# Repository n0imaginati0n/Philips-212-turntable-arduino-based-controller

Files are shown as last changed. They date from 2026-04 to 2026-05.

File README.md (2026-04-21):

# Philips-212-turntable-arduino-based-controller

A controller upgrade for the classic Philips 212 Hi-Fi turntable.
Replaces all touch switch, motor control, and auto-off functions with an Arduino Uno clone

Files include Arduino sketch and KiCad files

Fork of the

[lens42 project](https://github.com/lens42/Philips-212-turntable-arduino-based-controller)

[Details:](https://lensprojects.wordpress.com/2019/01/08/philips-212-turntable-controller-upgrade/)

# Improvements

* Use of the Ardino Pro Mini
* Self-made PCB. There are not so many parts there, it can be etched at home
* review schematics
    - add necessay loading on the LM780x. According to the datasheet, minimal current is 5..10 mA.
    - LM780x don't like to work on big capacitance load - they need protection diodes
    - small filtering caps on the sensors input to filter noise. input cirquit can be taken from original GA212 schematics
    - resistance in the MOSFET gate cirquit to limit the pulse current through MCU output
    - allow TH componets usage, reuse some items from original board
    - IP pins can be assigned better to make less croddings on the PCB
    - sensor button connections can be done better. but analog curcit rules should be taken into account
    - as I plan to etch teh single-layer board at home, I will use tow heatsinks for LM780x instead of the PCB polygons. There 
        is a lot of space under the PCB.
* Programming UART pins and reset button on the board. Pro Mini hasn't USB socket.
* Review the firmware
    - make it interactive
    - all initially predefined values can be set by UART
    - keep configuration values in the FLASH

# Arduino Power

Almost all Arduino boards has an LDO onboard. This LDO allows up to 16V input and can supply arduino and external cirquit 
with the +3.3V/+5V <150mA power according to the Arduino version. All the MCU ATMEGA328 allow both +3.3V and +5V power. The 
difference is that on lower voltage Arduino works stable with less crystal frequency. That is why +3.3V has 8MHz crystal and 
+5V has 16MHz crystal. Any version of the Arduino Pro Mini can safely be supplied with the +5V.

LM393 can operate with power in +2V..+36V range, means it can be perfectly powered from any version of the Arduino. It 
cosumes <20mA, this current is a maximal sink current and should be lower than that.

Unfortunately, my Arduino LDO is broken because of the previous experiments, that is why I kept the external LDO here and lead 
the +5V to the Arduino Vcc input. Vcc - is a direct way to teh Arduino power excluding on-baord LDO.

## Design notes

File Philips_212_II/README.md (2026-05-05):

---
title: Philips GA212 firmware
---

# Implementation description

This firmware implemented as a list of tasks. Each task has 'init' and 'loop' function.
They are called from 'init' and 'loop' functions of the sketch appropriately. It is not RTOS,
it has no guaranteed response time to events, but it still allows to execute many 
simultaneous functions. The only rules: don't block the execution and be fast. better 
split long operation over more than one calls of 'loop' task function. Tasks related to 
interrupts has interrupt handlers in their own compilation units.

## LEDs task

light LEDs according to the current mode.

## Autostop task

if motor is on, track the value of the photosensor and switch teh mode to OFF as fast as 
photosensor value will show end of plate. the sensing value stored in configuration and 
can be set from shell

## Buttons task

this task implements simple de-bouncing for buttons and changes the state accordingly to
pressed buttons. De-bouncing algorithm is pretty common: it waits until the bouncing stop, 
waits for some time, prove, that button strate kept pressed and sign about event the main 
loop. only pins D2 and D3 can generate interrupt in this MCU. all the state tracking done
manually using digitalRead()

## Speed task

this task loads appropriate potentiometer value, calculate necessary PWM value and set it 
to the motor acceleration. as potentiometers aren't really precise, they left to function 
in a specific range. i.e. their value after appropriate scaling will be added to the 
configuration stored value to get result acceleration. to make it working, the configuration 
value can be set from shell. software will monitor not a PWM, but a tacho value, which is 
measured in microseconds. 33 RPM has period approximately 26700 us, 45 RPM has period 
approximately 19250 us in my case. as PWM value going to be not absolute, but relative - 
increase to shortend measured period and decrease to extend it, it is important to evaluate 
new PWM value only once per period measurement. otherwise intertia will be introduced - the PWM 
value will be corrected multiple times per period measurement trying to correct period and 
overcomensate in result

## Shell task

this task is responsible for primitive shell available on serial programming port. the shell 
can print current configuration, set new configuration values, switch on debug monitoring. shell 
is asynchronous, that is why it can react with a small delay

# Implementation Status

- [x] LEDs task
  - [x] Implemntation
  - [x] Monitoring
- [x] Shell task
  - [x] Implementation
  - [x] Monitoring
- [x] Autostop task
  - [x] Implemntation
  - [x] Monitoring
- [x] Buttons task
  - [x] Implementation
  - [x] Monitoring
- [x] Speed task
  - [ ] Implementation
  - [x] Monitoring
- [x] Configuration
  - [x] EEPROM storage
  - [x] use by getter
  - [x] update by setters

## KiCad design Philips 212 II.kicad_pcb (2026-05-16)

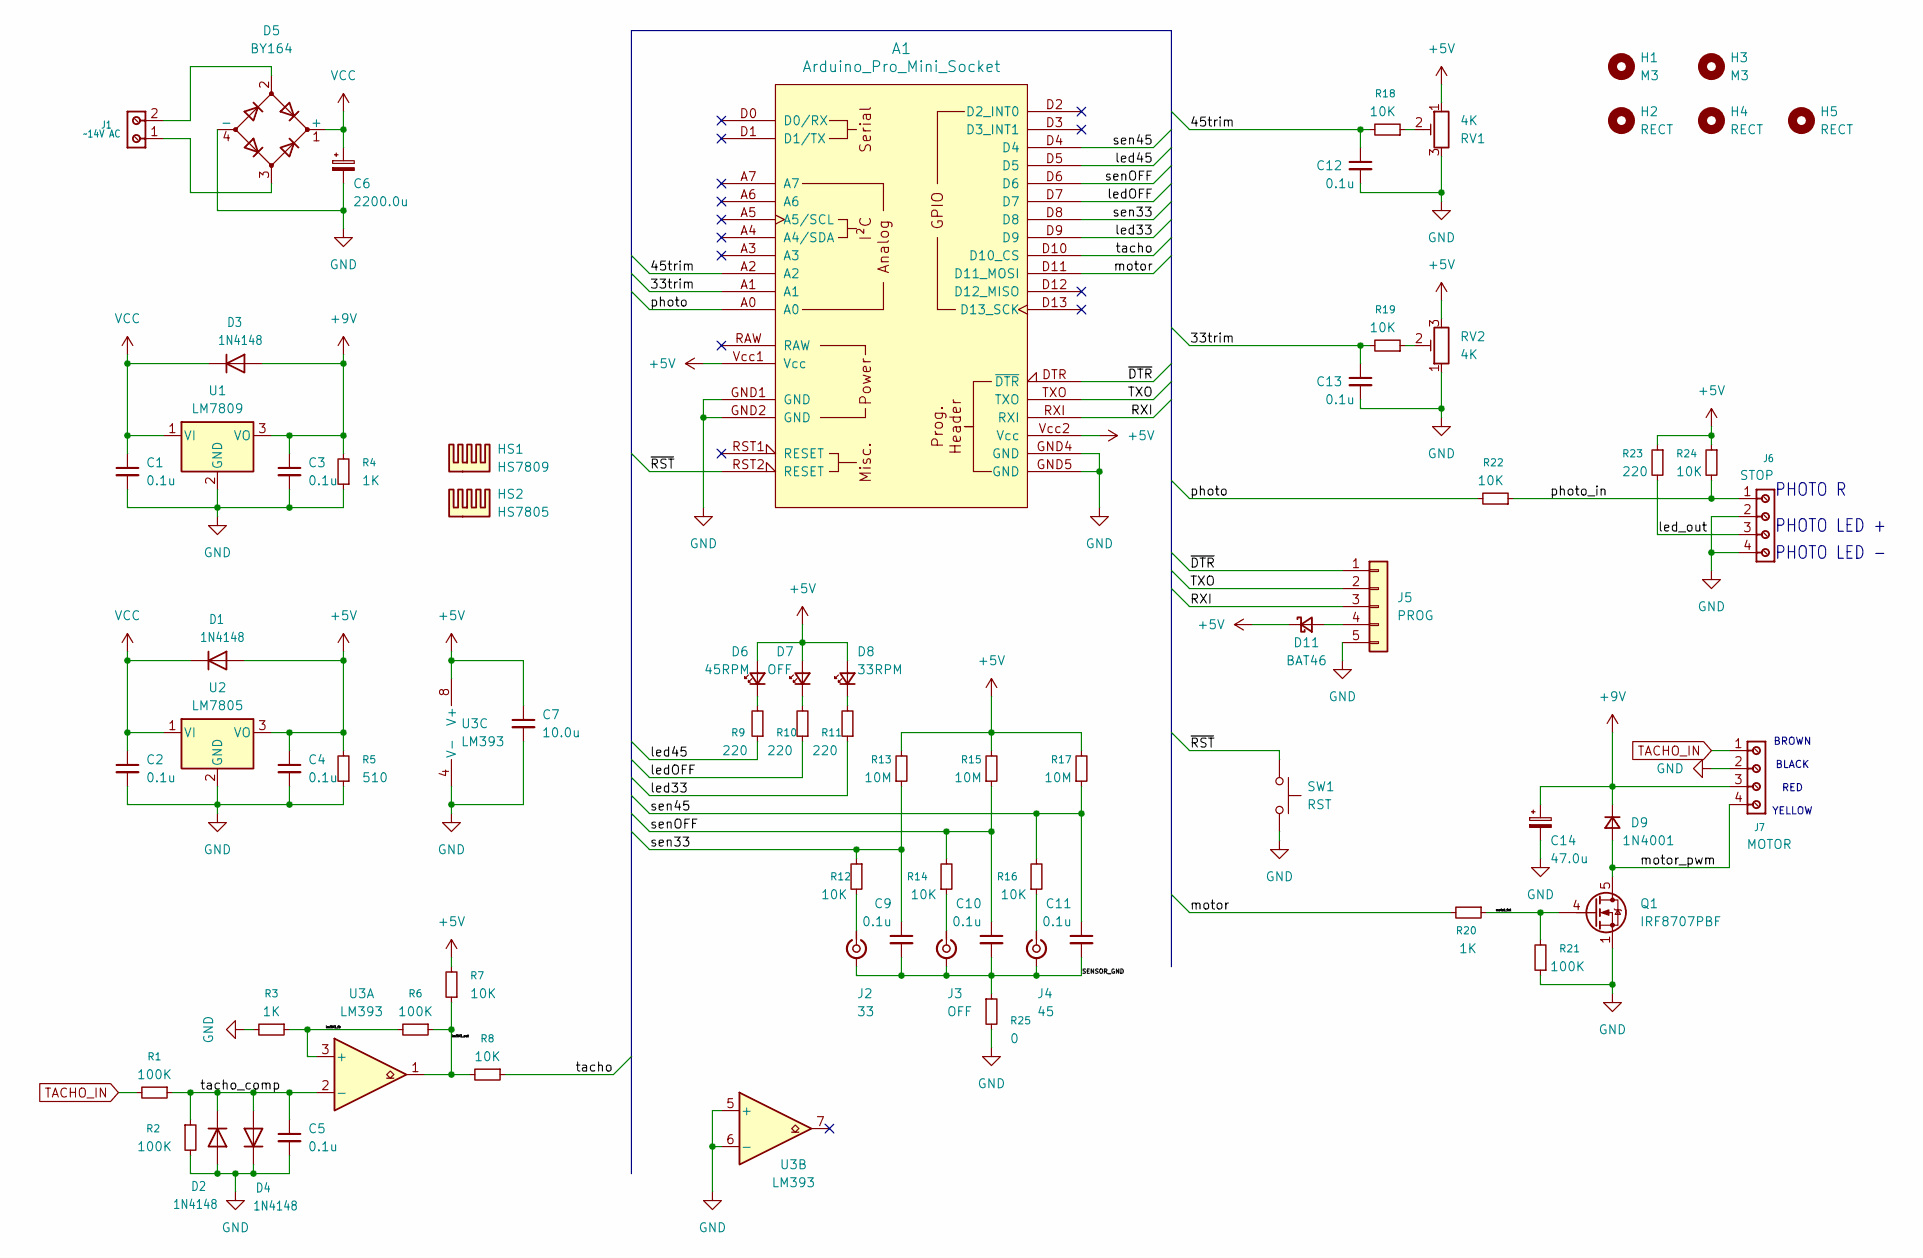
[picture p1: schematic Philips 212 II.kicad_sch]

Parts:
A1: Arduino_Pro_Mini_Socket
C1, C2, C3, C4, C5, C9, C10, C11, C12, C13: 0.1u; C_0805_2012Metric_Pad1.18x1.45mm_HandSolder
C6: 2200.0u; CP_Radial_D16.0mm_P7.50mm
C7: 10.0u; CP_Radial_D8.0mm_P3.50mm
C14: 47.0u; CP_Radial_D8.0mm_P3.50mm
D1, D3: 1N4148; D_MELF_Handsoldering
D2, D4: 1N4148; D_DO-35_SOD27_P7.62mm_Horizontal
D5: BY164; Diode_Bridge_19.0x3.5x10.0mm_P5.0mm
D6: 45RPM; LED_D5.0mm_Horizontal_O6.35mm_Z15.0mm
D7: OFF; LED_D5.0mm_Horizontal_O6.35mm_Z15.0mm
D8: 33RPM; LED_D5.0mm_Horizontal_O6.35mm_Z15.0mm
D9: 1N4001; D_DO-41_SOD81_P10.16mm_Horizontal
D11: BAT46; D_DO-35_SOD27_P7.62mm_Horizontal
H1, H3: M3; MountingHole_3.2mm_M3
H2, H4, H5: RECT; MountingHole_6mm
HS1: HS7809; FISHER-FK211-32_TO220_Horizontal
HS2: HS7805; FISHER-FK211-32_TO220_Horizontal
J1: ~14V AC; Altech_AK100_1x02_P5.00mm
J2: 33; Altech_AK100_1x02_P5.00mm
J3: OFF; Altech_AK100_1x02_P5.00mm
J4: 45; Altech_AK100_1x02_P5.00mm
J5: PROG; PinHeader_1x05_P2.54mm_Vertical
J6: STOP; Altech_AK100_1x04_P5.00mm
J7: MOTOR; Altech_AK100_1x04_P5.00mm
Q1: IRF8707PBF; PowerPAK_SO-8_Single
R1, R2, R21: 100K; R_0805_2012Metric_Pad1.20x1.40mm_HandSolder
R3: 1K; R_0805_2012Metric_Pad1.20x1.40mm_HandSolder
R4, R20: 1K; R_Axial_DIN0207_L6.3mm_D2.5mm_P7.62mm_Horizontal
R5: 510; R_Axial_DIN0207_L6.3mm_D2.5mm_P7.62mm_Horizontal
R6: 100K; R_Axial_DIN0207_L6.3mm_D2.5mm_P7.62mm_Horizontal
R7, R12, R14, R16, R18, R19, R22, R24: 10K; R_0805_2012Metric_Pad1.20x1.40mm_HandSolder
R8: 10K; R_Axial_DIN0207_L6.3mm_D2.5mm_P7.62mm_Horizontal
R9, R10, R11, R23: 220; R_Axial_DIN0207_L6.3mm_D2.5mm_P7.62mm_Horizontal
R13, R15, R17: 10M; R_Axial_DIN0411_L9.9mm_D3.6mm_P15.24mm_Horizontal
R25: 0; R_0805_2012Metric_Pad1.20x1.40mm_HandSolder
RV1, RV2: 4K; Potentiometer_ACP_CA14V-15_Vertical_Hole
SW1: RST; SW_PUSH_6mm
U1: LM7809; TO-220-3_Horizontal_TabDown
U2: LM7805; TO-220-3_Horizontal_TabDown
U3: LM393; SOIC-8_3.9x4.9mm_P1.27mm

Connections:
+5V: A1.Vcc1 (Vcc), A1.Vcc2 (Vcc), C4.1, C7.1, D1.2 (A), D6.2 (A), D7.2 (A), D8.2 (A), D11.1 (K), R5.2, R7.2, R13.2, R15.2, R17.2, R23.1, R24.1, RV1.1, RV2.3, U2.3 (VO), U3.8 (V+)
+9V: C3.1, C14.1, D3.2 (A), D9.1 (K), J7.3, R4.2, U1.3 (VO)
/33trim: A1.A1, C13.1, R19.2
/45trim: A1.A2, C12.1, R18.2
/RXI: A1.RXI, J5.3
/SENSOR_GND: C9.2, C10.2, C11.2, J2.2 (Ext), J3.2 (Ext), J4.2 (Ext), R25.1
/TXO: A1.TXO, J5.2
/led33: A1.D9, R11.1
/led45: A1.D5, R9.1
/ledOFF: A1.D7, R10.1
/led_out: J6.3, R23.2
/lm393_fb: R3.1, R6.2, U3.3 (+)
/lm393_out: R6.1, R7.1, R8.2, U3.1
/motor: A1.D11 (D11_MOSI), R20.2
/motor_pwm: D9.2 (A), J7.4, Q1.5 (D)
/motot_fet: Q1.4 (G), R20.1, R21.2
/photo: A1.A0, R22.2
/photo_in: J6.1, R22.1, R24.2
/sen33: A1.D8, C9.1, R12.1, R13.1
/sen45: A1.D4, C11.1, R16.2, R17.1
/senOFF: A1.D6, C10.1, R14.2, R15.1
/tacho: A1.D10 (D10_CS), R8.1
/tacho_comp: C5.1, D2.1 (K), D4.2 (A), R1.1, R2.1, U3.2 (-)
/~DTR: A1.DTR (~DTR), J5.1
/~RST: A1.RST2 (RESET), SW1.1
GND: A1.GND1 (GND), A1.GND2 (GND), A1.GND4 (GND), A1.GND5 (GND), C1.2, C2.2, C3.2, C4.2, C5.2, C6.2, C7.2, C12.2, C13.2, C14.2, D2.2 (A), D4.1 (K), D5.4 (-), J5.5, J6.2, J6.4, J7.2, Q1.1 (S), Q1.2 (S), Q1.3 (S), R2.2, R3.2, R4.1, R5.1, R21.1, R25.2, RV1.3, RV2.1, SW1.2, U1.2 (GND), U2.2 (GND), U3.4 (V-), U3.5 (+), U3.6 (-)
unnamed: D5.2, J1.2
unnamed: D5.3, J1.1
unnamed: D6.1 (K), R9.2
unnamed: D7.1 (K), R10.2
unnamed: D8.1 (K), R11.2
unnamed: D11.2 (A), J5.4
unnamed: J2.1 (In), R12.2
unnamed: J3.1 (In), R14.1
unnamed: J4.1 (In), R16.1
unnamed: R18.1, RV1.2
unnamed: R19.1, RV2.2
TACHO_IN: J7.1, R1.2
VCC: C1.1, C2.1, C6.1, D1.1 (K), D3.1 (K), D5.1 (+), U1.1 (VI), U2.1 (VI)

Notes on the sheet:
PHOTO R
PHOTO LED -
BROWN BLACK RED YELLOW
PHOTO LED +

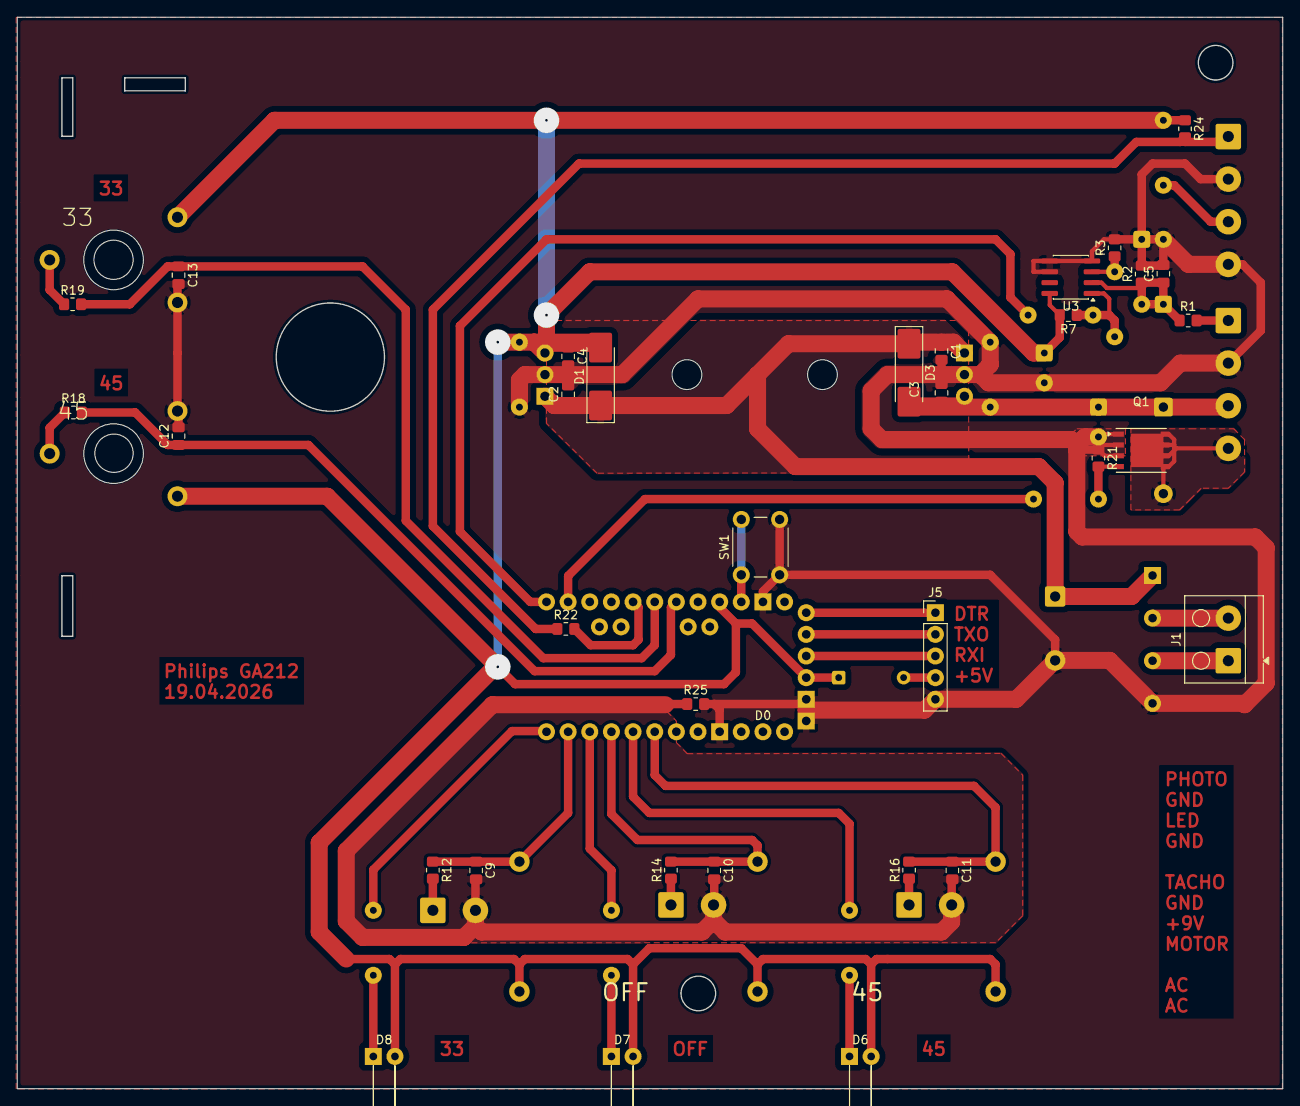
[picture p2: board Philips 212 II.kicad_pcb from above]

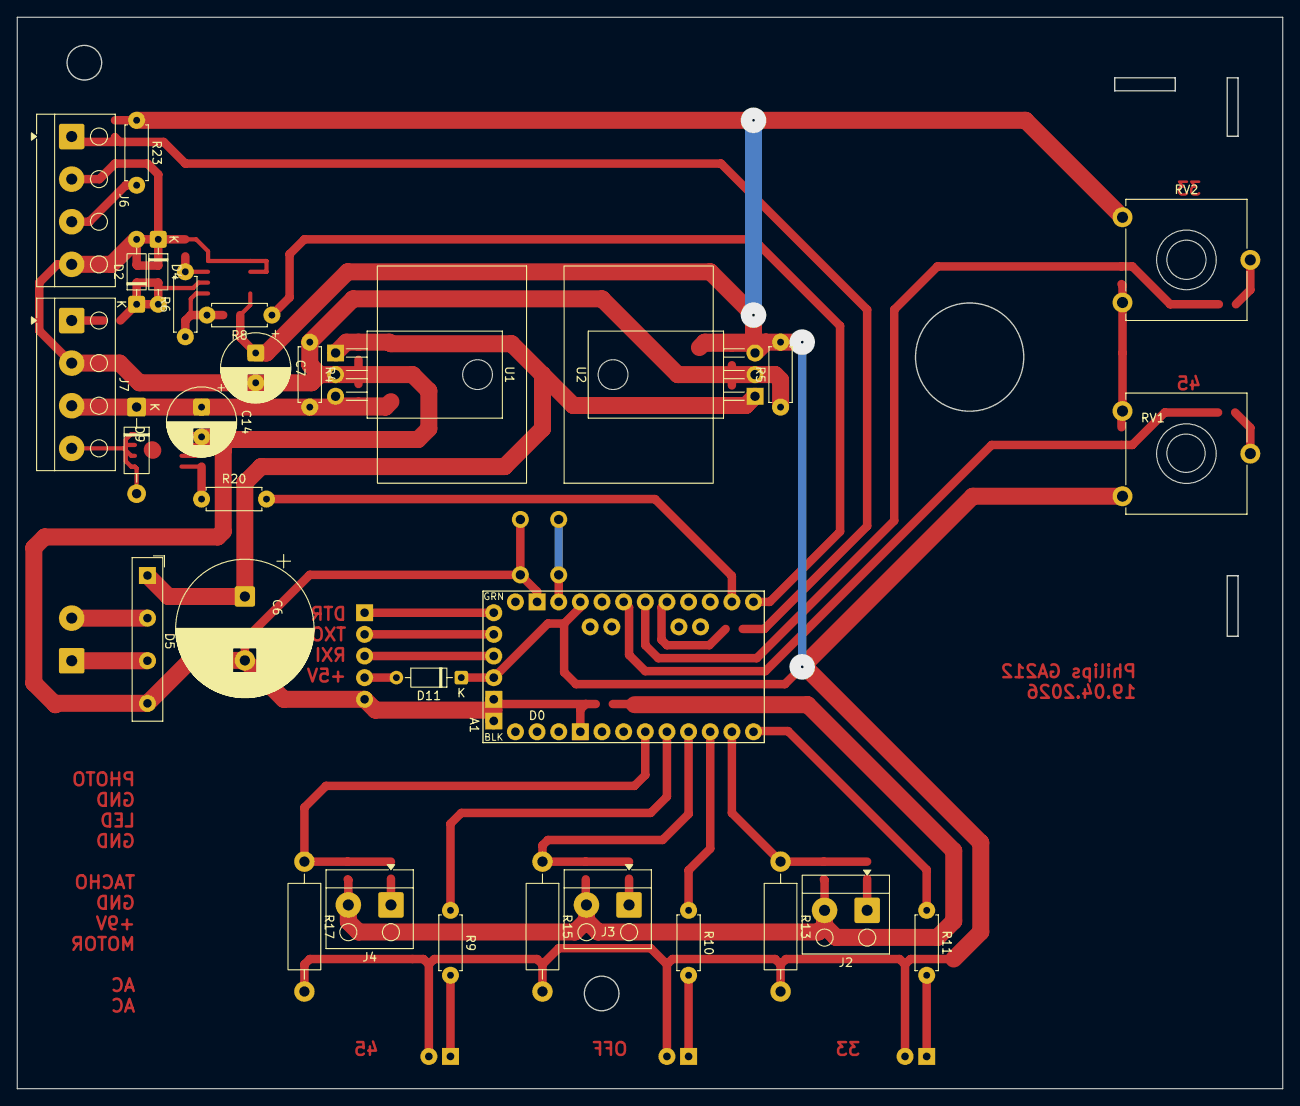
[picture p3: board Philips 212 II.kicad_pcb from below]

Board: 2 copper layers, 148.5 x 125.7 mm, 65 parts (32 on the bottom side), 39 nets.

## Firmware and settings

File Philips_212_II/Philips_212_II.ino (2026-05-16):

#include <Arduino.h>

#include "appstate.h"

#include "task_leds.h"
#include "task_autostop.h"
#include "task_shell.h"
#include "task_speed.h"
#include "task_buttons.h"
#include "task_tacho.h"

void setup() {
  analogReference(DEFAULT);

  status_init();

  task_leds_init();
  task_autostop_init();
  task_speed_init();
  task_buttons_init();
  task_shell_init();
  task_tacho_init();
}

void loop() {
  task_buttons_loop();
  task_autostop_loop(); // autostop can overcome the buttons
  task_leds_loop();     // leds should display actual state

  task_tacho_loop();
  task_speed_loop();    // motor works as it defined earlier

  // asynchronous, not related to the order as it offers no 
  // possibility to modify the state or measured values
  task_shell_loop();    
}

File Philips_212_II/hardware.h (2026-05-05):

#ifndef _HARDWARE_H
#define _HARDWARE_H

// autostop photosensor input
#define AIN_PHOTO   14
// 33RPM analog potentiometer input
#define AIN_33TRIM  15
// 45RPM analog potentiometer input
#define AIN_45TRIM  16

// 45RPM sensor digital input
#define DIN_SEN45   4
// STOP sensor digital input
#define DIN_SENOFF  6
// 33RPM sensor digital input
#define DIN_SEN33   8
// tacho digital input
#define DIN_TACHO   10

// 45RPM led
#define DOUT_LED45  5
// STOP led
#define DOUT_LEDOFF 7
// 33RPM led
#define DOUT_LED33  9

// motor speed PWM output
#define PWM_MOTOR   11

#endif // _HARDWARE_H

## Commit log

2026-04-21 version II of the schematics and board
    [Philips 212 II.kicad_pcb, Philips 212 II.kicad_sch]
2026-05-16 attempt to make analytical PID paramns
    [Philips 212 II.kicad_pcb, Philips 212 II.kicad_sch]
